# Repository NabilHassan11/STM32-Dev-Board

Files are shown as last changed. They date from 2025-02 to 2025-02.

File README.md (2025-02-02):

# STM32-Dev-Board
# STM32F103C8T6 Development Board

## Overview
This is a custom **STM32F103C8T6 development board** designed for embedded systems and firmware development. It provides an easy-to-use platform for programming, debugging, and prototyping STM32-based projects.

## Features
✅ **Microcontroller:** STM32F103C8T6 (ARM Cortex-M3, 72MHz, 64KB Flash, 20KB RAM)  
✅ **Power Input:** USB-B Micro for power and data transfer  
✅ **Programming & Debugging:** SWD header for easy debugging with ST-Link  
✅ **Reset & Boot Buttons:** Tactile push buttons for **RESET** and **BOOT mode selection**  
✅ **Connectivity:**  
   - **USART header & I2C ** for serial communication  
   - **Multiple GPIO breakout pins** for external peripherals  
✅ **Power Regulation:** Onboard **LDO voltage regulator** for stable 3.3V operation  
✅ **Crystal Oscillator:** 16MHz main clock 

## Applications
- Embedded systems development
- IoT prototyping
- Motor control & robotics
- Educational & hobby projects

## Repository Contents
📁 **Hardware:** KiCad design files, schematics, and PCB layout
📁 **Documentation:** BOM, assembly guide, and pinout diagrams  

---
### Author
**Nabil Hassan**

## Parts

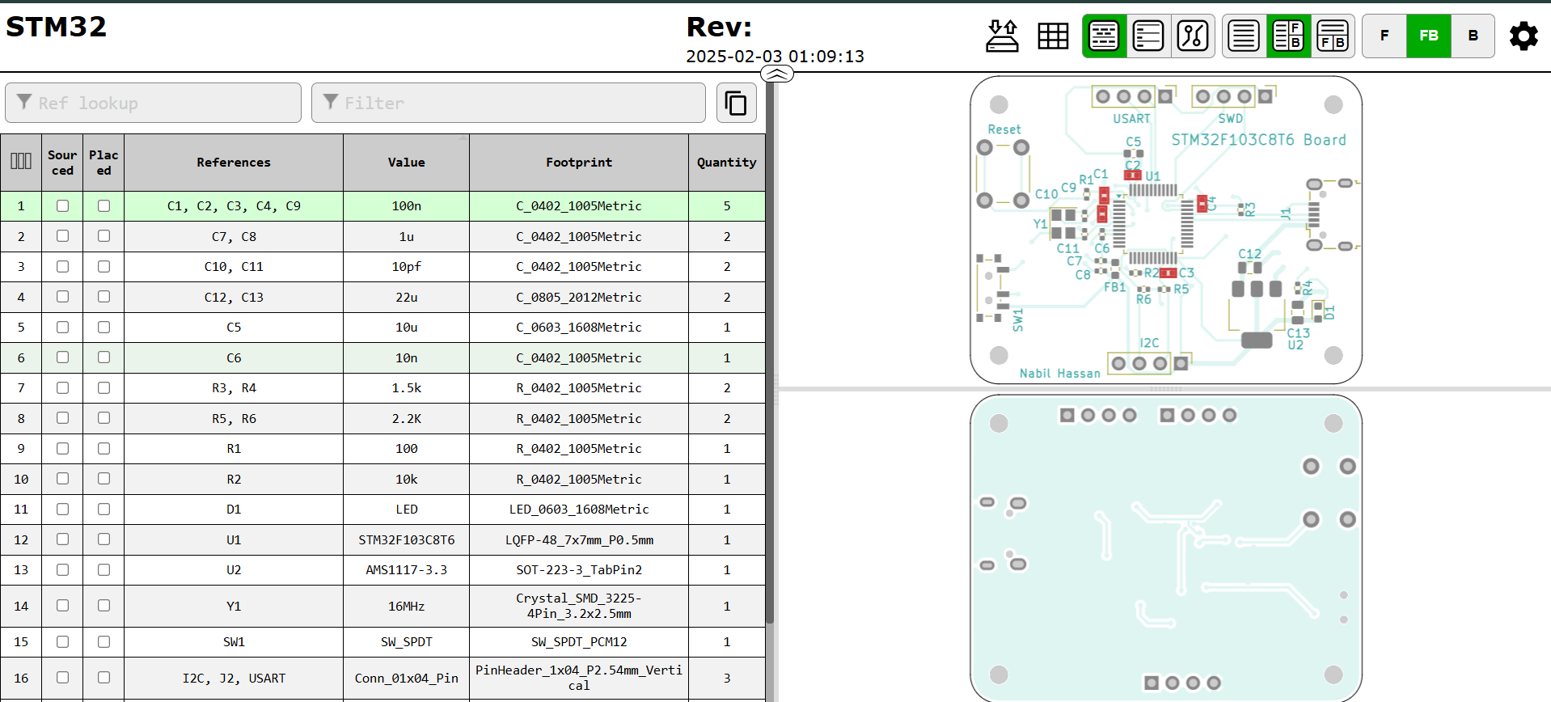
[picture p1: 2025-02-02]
BOM.png

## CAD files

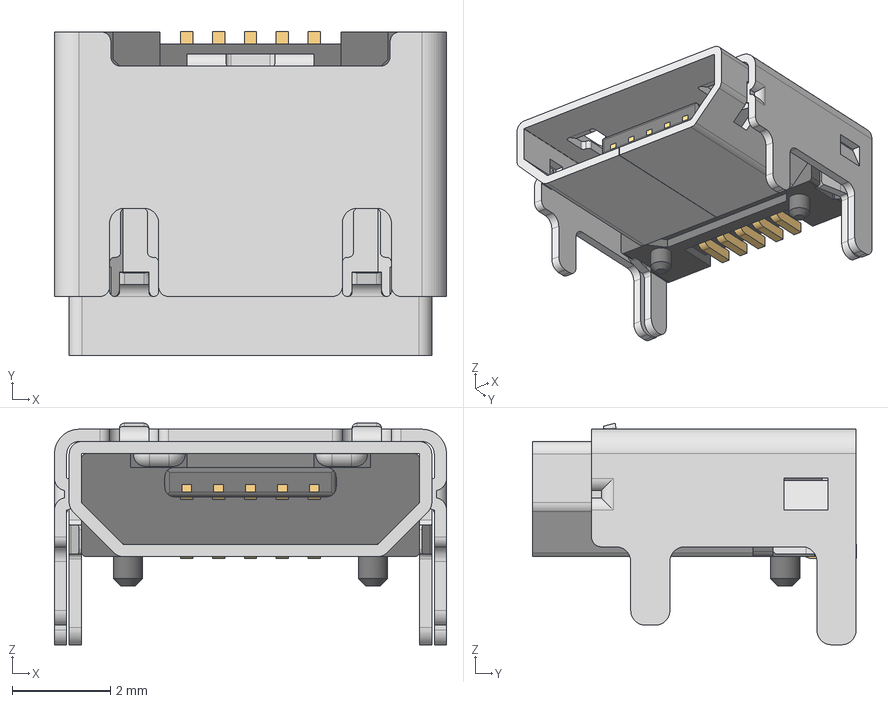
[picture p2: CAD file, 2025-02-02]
629105150521 (rev1).stp
8.00 x 6.60 x 4.52 mm
629105150521_Housing
629105150521_Pin1 x 4
629105150521_Pin2
629105150521_Shielding2
629105150521_Shielding

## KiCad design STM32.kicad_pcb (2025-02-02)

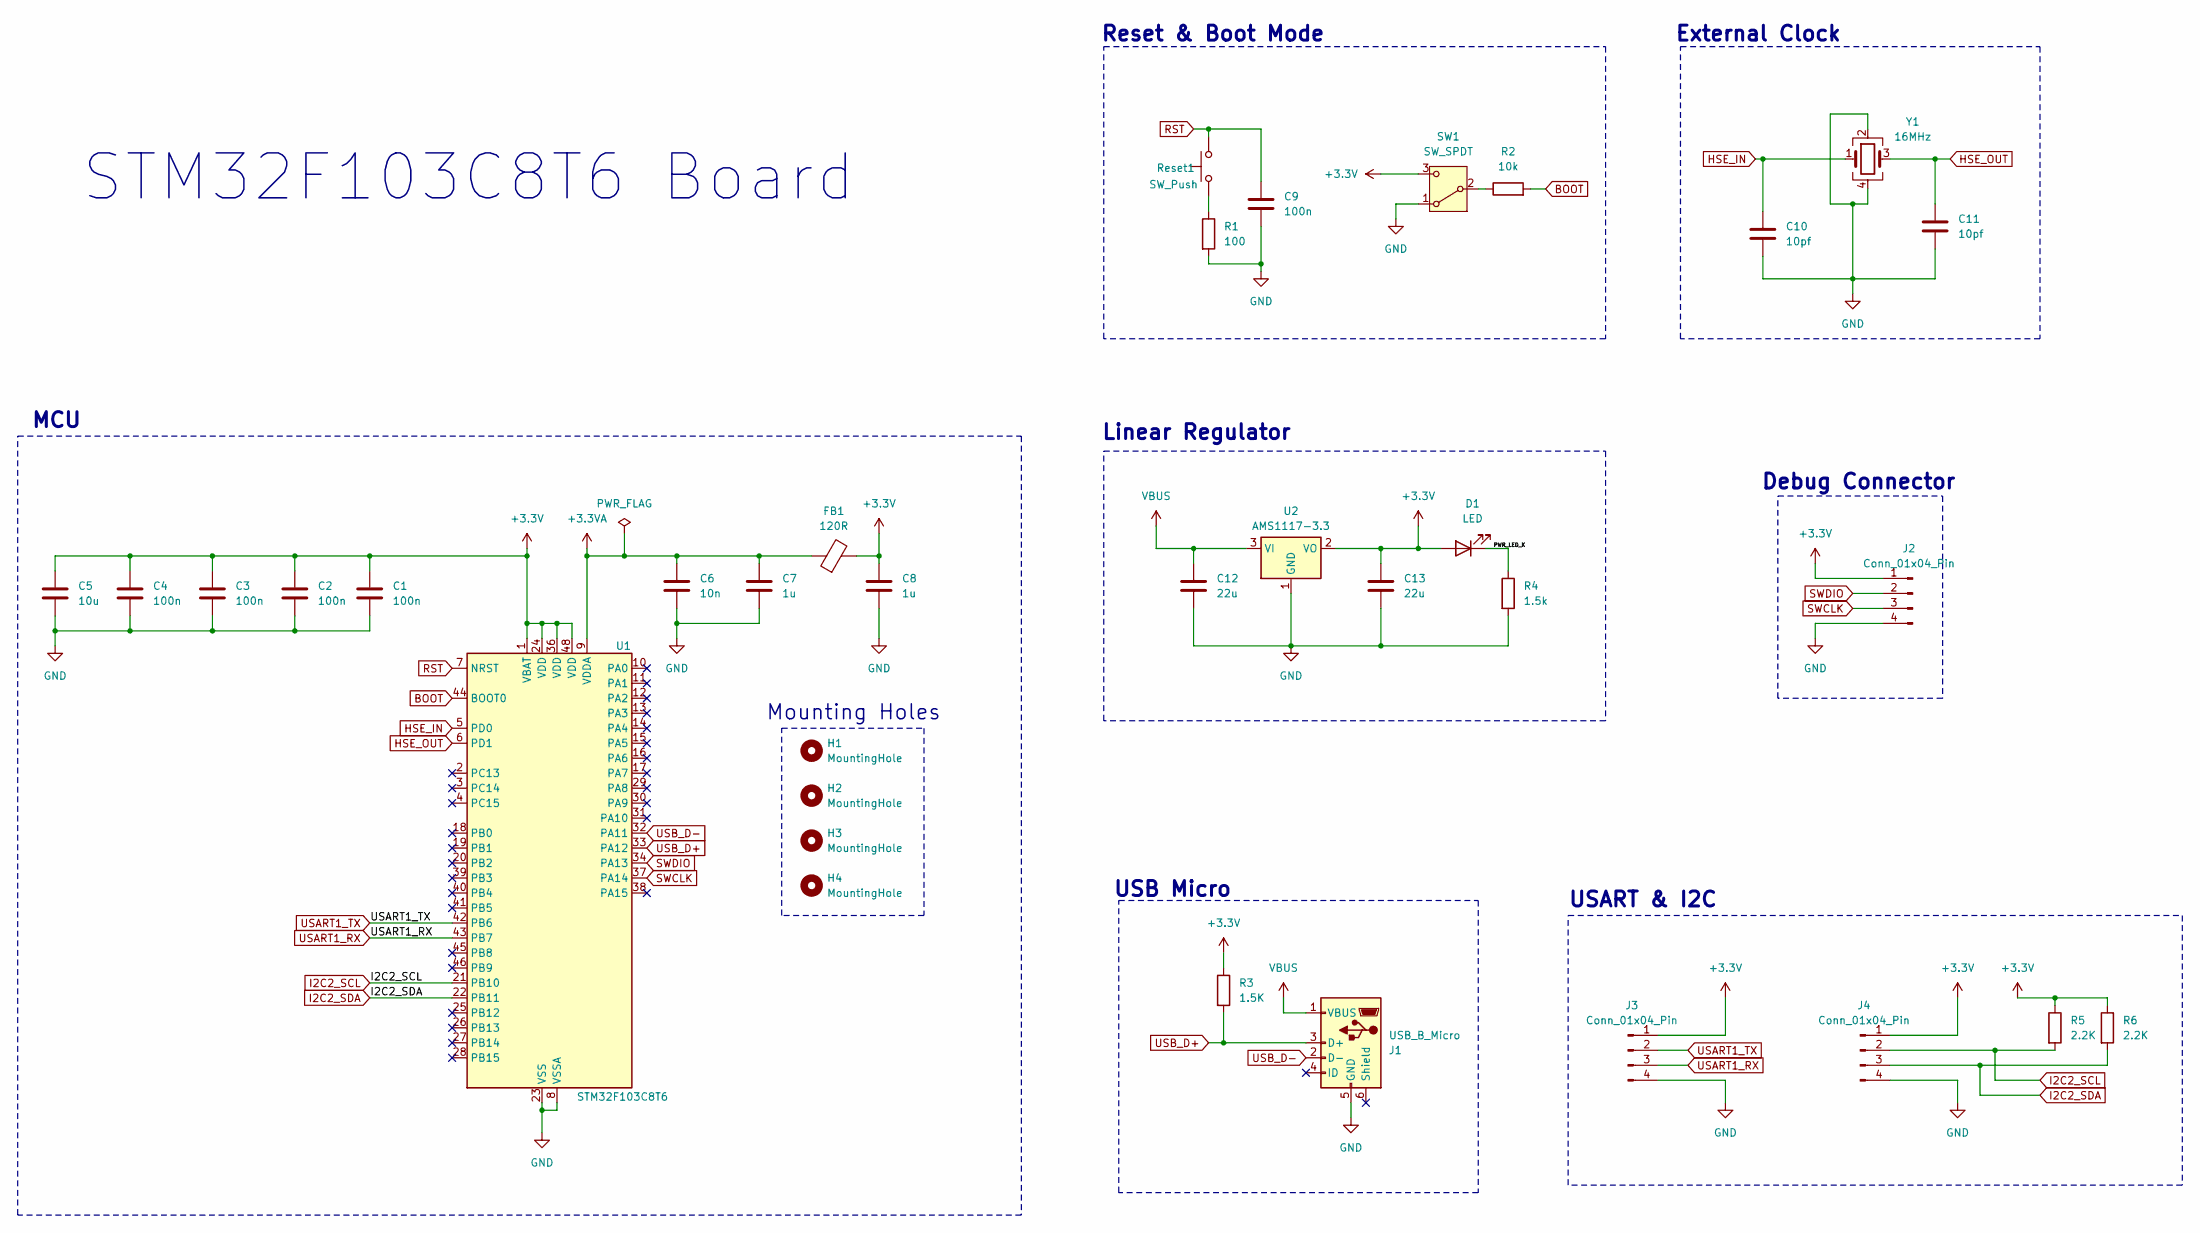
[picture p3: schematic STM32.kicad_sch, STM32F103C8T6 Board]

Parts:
C1, C2, C3, C4, C9: 100n; C_0402_1005Metric
C5: 10u; C_0603_1608Metric
C6: 10n; C_0402_1005Metric
C7, C8: 1u; C_0402_1005Metric
C10, C11: 10pf; C_0402_1005Metric
C12, C13: 22u; C_0805_2012Metric
D1: LED; LED_0603_1608Metric
FB1: 120R; L_0603_1608Metric
H1, H2, H3, H4: MountingHole; MountingHole_2.2mm_M2
J1: USB_B_Micro; USB_Micro-B_Wuerth_629105150521
J2, J3, J4: Conn_01x04_Pin; PinHeader_1x04_P2.54mm_Vertical
R1: 100; R_0402_1005Metric
R2: 10k; R_0402_1005Metric
R3: 1.5K; R_0402_1005Metric
R4: 1.5k; R_0402_1005Metric
R5, R6: 2.2K; R_0402_1005Metric
Reset1: SW_Push; SW_PUSH_6mm
SW1: SW_SPDT; SW_SPDT_PCM12
U1: STM32F103C8T6; LQFP-48_7x7mm_P0.5mm
U2: AMS1117-3.3; SOT-223-3_TabPin2
Y1: 16MHz; Crystal_SMD_3225-4Pin_3.2x2.5mm

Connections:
+3.3V: C1.1, C2.1, C3.1, C4.1, C5.1, C8.1, C13.1, D1.2 (A), FB1.2, J2.1, J3.1, J4.1, R3.1, R5.1, R6.1, SW1.3 (C), U1.1 (VBAT), U1.24 (VDD), U1.36 (VDD), U1.48 (VDD), U2.2 (VO); also elsewhere on the board
+3.3VA: C6.1, C7.1, FB1.1, U1.9 (VDDA)
/PWR_LED_K: D1.1 (K), R4.1
BOOT: R2.2, U1.44 (BOOT0)
GND: C1.2, C2.2, C3.2, C4.2, C5.2, C6.2, C7.2, C8.2, C9.2, C10.2, C11.2, C12.2, C13.2, J1.5 (GND), J2.4, J3.4, J4.4, R1.2, R4.2, SW1.1 (A), U1.8 (VSSA), U1.23 (VSS), U1.35 (VSS), U1.47 (VSS), U2.1 (GND), Y1.2, Y1.4; also elsewhere on the board
HSE_IN: C10.1, U1.5 (PD0), Y1.1
HSE_OUT: C11.1, U1.6 (PD1), Y1.3
I2C2_SCL: J4.2, R5.2, U1.21 (PB10); also elsewhere on the board
I2C2_SDA: J4.3, R6.2, U1.22 (PB11); also elsewhere on the board
unnamed 9: R1.1, Reset1.1; also elsewhere on the board
unnamed: R2.1, SW1.2 (B)
RST: C9.1, Reset1.2, U1.7 (NRST); also elsewhere on the board
SWCLK: J2.3, U1.37 (PA14)
SWDIO: J2.2, U1.34 (PA13)
USART1_RX: J3.3, U1.43 (PB7); also elsewhere on the board
USART1_TX: J3.2, U1.42 (PB6); also elsewhere on the board
USB_D+: J1.3 (D+), R3.2, U1.33 (PA12)
USB_D-: J1.2 (D-), U1.32 (PA11)
VBUS: C12.1, J1.1 (VBUS), U2.3 (VI)

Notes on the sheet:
STM32F103C8T6 Board
Linear Regulator
USART & I2C
Reset & Boot Mode
External Clock
MCU
USB Micro
Mounting Holes
Debug Connector

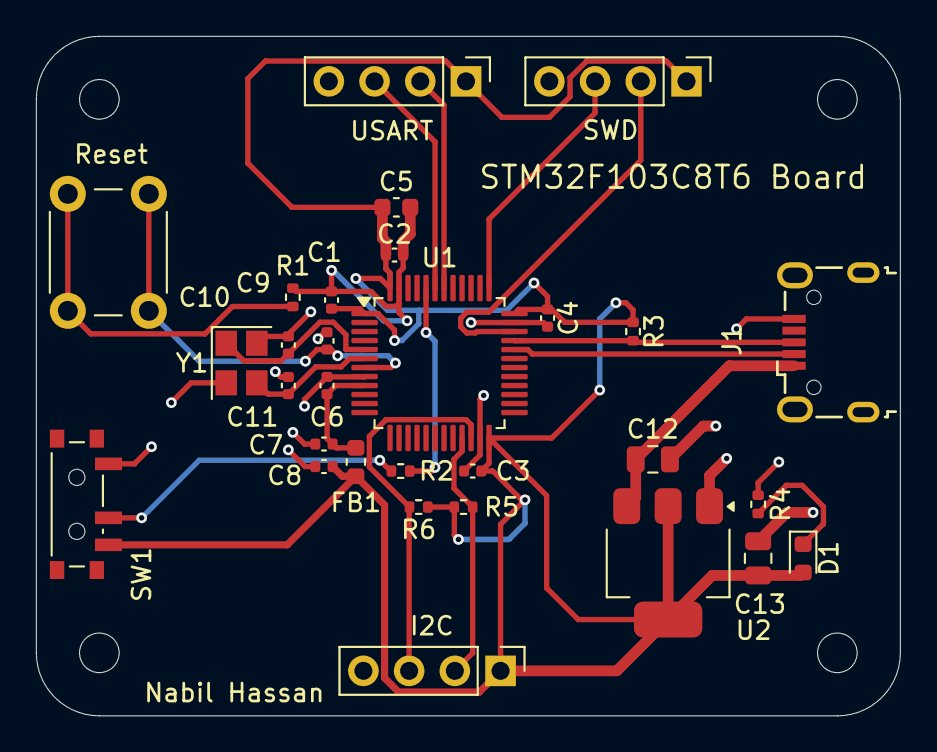
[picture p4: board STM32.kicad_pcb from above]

Board: 2 copper layers, 48.0 x 37.8 mm, 34 parts (0 on the bottom side), 19 nets.

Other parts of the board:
I2C: Conn_01x04_Pin; PinHeader_1x04_P2.54mm_Vertical
Reset: SW_Push; SW_PUSH_6mm
USART: Conn_01x04_Pin; PinHeader_1x04_P2.54mm_Vertical

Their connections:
+3.3V: I2C.1, USART.1; also elsewhere on the board
GND: I2C.4, USART.4; also elsewhere on the board
I2C2_SCL: I2C.2; also elsewhere on the board
I2C2_SDA: I2C.3; also elsewhere on the board
unnamed 9: Reset.1; also elsewhere on the board
RST: Reset.2; also elsewhere on the board
USART1_RX: USART.3; also elsewhere on the board
USART1_TX: USART.2; also elsewhere on the board
